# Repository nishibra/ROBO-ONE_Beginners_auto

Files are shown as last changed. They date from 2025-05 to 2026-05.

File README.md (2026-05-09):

# ROBO-ONE Beginners auto

### ROBO-ONE Beginners 競技規則　[競技規則](https://github.com/nishibra/ROBO-ONE_Beginners)
### ROBO-ONE Beginners auto　[機械設計](Mechanical_Design.md)
### ROBO-ONE Beginners auto　[電子回路](Electronic_Circuit.md)

-2025年8月22日 シリアル通信用に分配器を追加しました。
 
### ROBO-ONE Beginners auto　[ソフトウェア](Software.md)

-2026年2月20日　●ToFセンサーで相手を探すサンプル追加　●近藤科学のコントローラーKRS-5FHを使うサンプル追加

-2026年5月9日　●倒立伸子のサンプルプログラムを追加
### ROBO-ONE Beginners movies [動画](https://www.youtube.com/channel/UCuxCMnABbm_D5GusLxcCyIQ)

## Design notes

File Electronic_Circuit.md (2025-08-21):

# ROBO-ONE Beginners 自律型ロボット(RasPi Pico)　Electronic Circuit
## コンセプト
自律型でビジョンを除く必要なセンサーを搭載しました。はんだ付けは極力少なくするようにしました。入出力の拡張も余裕を持たせました。以下は電子回路部分の完成写真です。

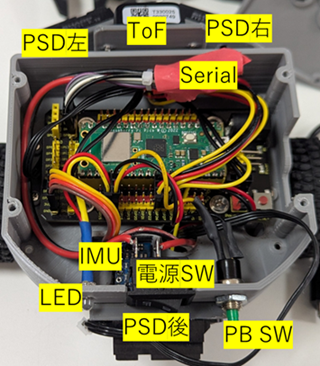
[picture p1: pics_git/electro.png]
  

### Pico拡張ボード
入出力Pinが電源とともに出力されているのでとても便利です。黒:gnd 赤:3.3v 黄:信号

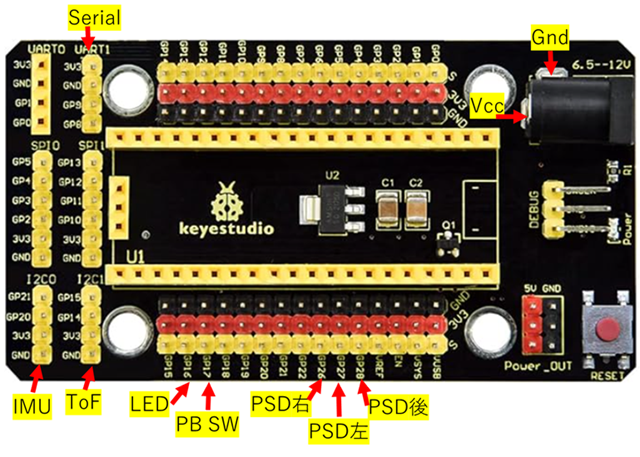
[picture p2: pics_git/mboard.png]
  

[拡張ボードの購入先例](https://www.amazon.co.jp/dp/B0B45YWJH7?ref=ppx_yo2ov_dt_b_fed_asin_title)

### Raspberry Pi Pico
PicoやPico w,pico2,pico2wなどを使用します。PicoW、Pico2Wを使用すれば、Bluetoothによるコントロールプログラムが利用できます。

[Pico-series 仕様](https://www.raspberrypi.com/documentation/microcontrollers/pico-series.html#pico-2-family)

[Picoの購入先例](https://akizukidenshi.com/catalog/g/g117947/)

### Serial変換I/F
サーボモーターを使用するためのシリアル通信を全二重通信から半二重通信に変換するボードです。

[Serial変換I/Fの購入先](https://www.besttechnology.co.jp/modules/onlineshop/index.php?fct=photo&p=299)

#### 配線方法
シリアル変換I/Fの配線状態です。(シリアル変換I/Fボードは仕様変更がありますので配線に当たっては必ずマニアルでご確認ください。)
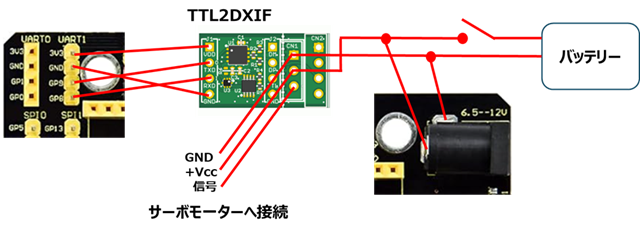
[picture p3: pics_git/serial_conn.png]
serial


(2025年8月22日追加変更)
この配線では回路ではシリアル変換I/Fボードに配線が集中するので分配器を追加しました。シリアル変換I/Fボード側は拡張基板から電源が供給されるので配線はシンプルになります。

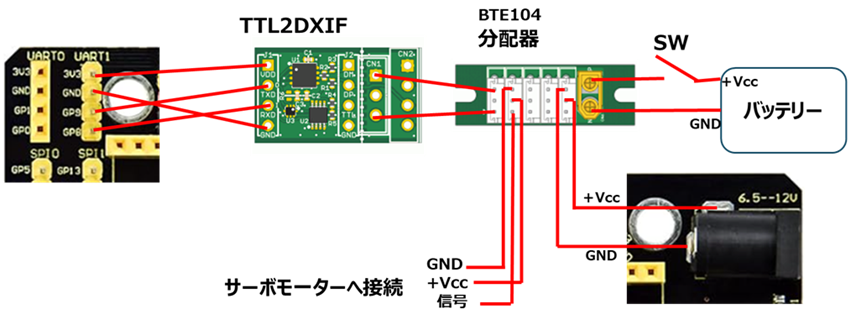
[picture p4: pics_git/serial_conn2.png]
serial


分配器はコネクターをはんだ付けしていないキットを購入すればコネクターの変更によって以下のように近藤科学のサーボや電源コネクターに対応することができます。
  
[分配器の購入先](https://www.besttechnology.co.jp/modules/onlineshop/index.php?fct=photo&p=317)

分配器  

拡張基板に電源供給するためのコネクターをはんだ付けしておきます。コネクターはラジコン用に使われているもので、分配器に接続します。

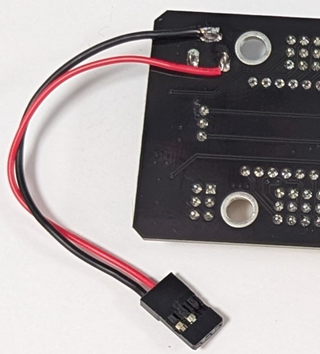
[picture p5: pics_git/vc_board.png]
  

これらを接続すると以下のようになります。

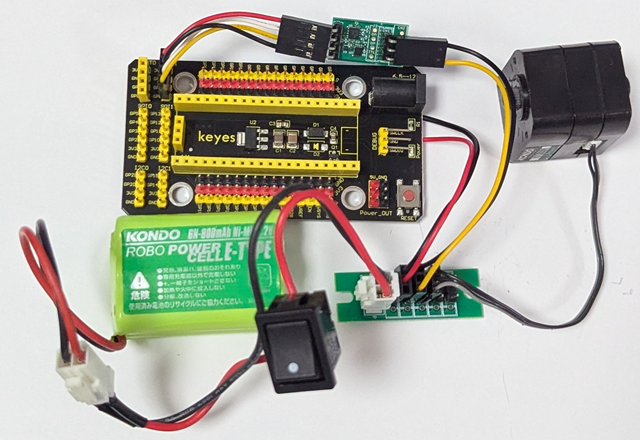
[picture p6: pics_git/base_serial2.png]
serial
  

シリアル変換I/Fボードは拡張基板のシリアルポート1に接続します。
全てのコネクターは方向を間違えないように挿してください。破損の原因となります。

コネクターの作り方については以下のサイトなどをご参照ください。

[コネクターの作り方](https://flyingcattokyo.sakura.ne.jp/MN-016/aa_mn-016.htm)

### PSDセンサー(SHARP製 GP2Y0A21YK0F)
PSD（Position Sensitive Detector）は光が当たった位置に応じて、アナログ信号を出力する受光素子で、距離を計測するセンサーです。出力はアナログ電圧ですのでADC端子に接続します。黒:gnd　赤:3.3v  黄:信号で、ケーブルは黒:gnd　赤:3.3v  白:信号に対応します。このセンサーの推奨電圧は5Vですが3.3Vでも問題なく動作しています。

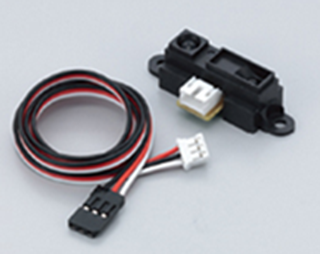
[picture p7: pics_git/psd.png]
psd
  

[購入先](https://kondo-robot.com/product/02002)
```
右　 GP26
左   GP27
後ろ GP28
に接続します。接続方向を間違えないようにしてください。
```
### ToFセンサー(TF-Luna)
光を発射し、それが反射して戻ってくるまでの時間を計測することで、距離を測定するToF(Time of Flight)センサーです。比較的長距離の距離の計測に使用します。このセンサーでは3m程度まで測定できます。

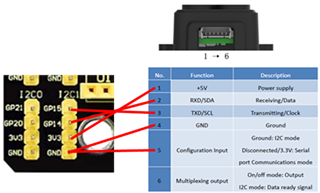
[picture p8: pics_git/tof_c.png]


推奨電圧は5Vですが、3.3Vでも動作を確認しました。

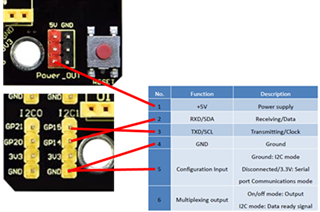
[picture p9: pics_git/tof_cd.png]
  

動作が不安定な場合は拡張ボードから5V電圧が出ていますのでこちらから給電してください。

[購入先](https://www.amazon.co.jp/dp/B087N2JRJ9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)
```
I2C1に接続します。
GP15    scl
GP14    sda
3V3     Vcc
GND     gnd
```

### IMU　9軸センサー(BNO055)
IMU(Inertial Measurement Unit)は、慣性計測装置のことで、3次元の慣性運動（並進運動と回転運動）を検出するために、加速度センサーと角速度（ジャイロ）センサーを組み合わせた装置です。ここではロボットの姿勢(オイラー角)を計測するために使用します。I2C通信で使用します。基板面に垂直方向がヨー軸で基板の長い面に平行な方向がロール軸、短い面に平行な軸がピッチ軸となります。

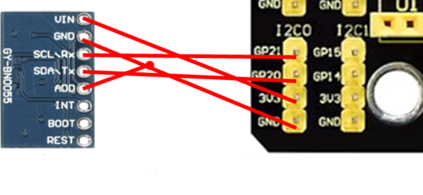
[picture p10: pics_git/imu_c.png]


BNO055ブレークアウトボードにはいろいろあるようなので使用に当たっては注意が必要です。
うまく動作しない場合は以下のサイトをご参照ください。

[モーションセンサBNO055が動かない,I2C接続で認識されないとき](https://trhk.exblog.jp/30642762)

[購入先](https://www.amazon.co.jp/BNO055-%E7%B5%B6%E5%AF%BE%E6%96%B9%E5%90%91%E3%82%BB%E3%83%B3%E3%82%B5%E3%83%BC-%E3%83%9C%E3%83%BC%E3%83%89%E8%A7%92%E5%BA%A6-%E3%82%B8%E3%8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)
```
I2C0に接続します。
GP21    scl
GP20    sda
3V3      Vcc
GND    gnd
```
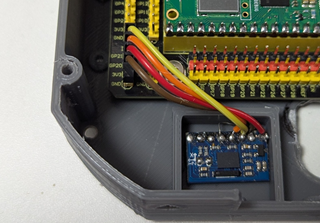
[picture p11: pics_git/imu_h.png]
  

以下のボードも確認しました。同じプログラムで動作します。

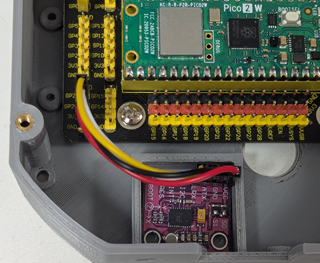
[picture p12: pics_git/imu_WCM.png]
WCMCU055
 

[WCMCU055の購入先](https://www.amazon.co.jp/inscriptions-BNO055-%E3%82%A4%E3%83%B3%E3%83%86%E3%83%AA%E3%82%B8%E3%82%A7%E3%83%B3%E3%83%88-%E5%A7%BF%E5%8B%A2%E3%82%BB%E3%83%B3%E3%82%B5%E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)

使い方は[こちら](https://www.davidpilling.com/wiki/index.php/BNO055)をご参照ください。

秋月電子のBNO055使用9軸センサフュージョンモジュールもテストして見ました。

[秋月電子BNO055の購入先](https://akizukidenshi.com/catalog/g/g116996/)

ボード上でプルアップされていないので、SDA,SCL端子を2kΩ程度の抵抗でプルアップしてください。同じプログラムで動作します。

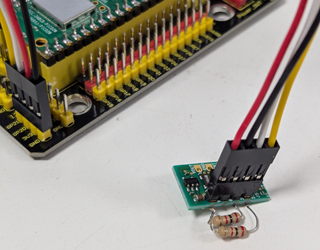
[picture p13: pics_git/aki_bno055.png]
aki_bno055


### Push ボタンSW
押しボタンスイッチです。入力として使います。1KΩ程度の抵抗を追加し、GP17に接続します。

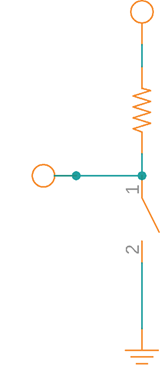
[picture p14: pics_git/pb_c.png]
  
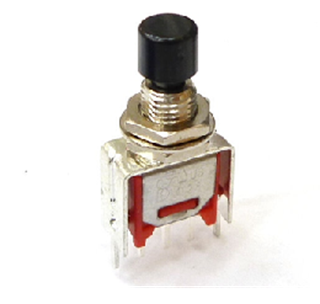
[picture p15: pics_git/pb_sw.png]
  
 
[購入先](https://akizukidenshi.com/catalog/g/g104367/)

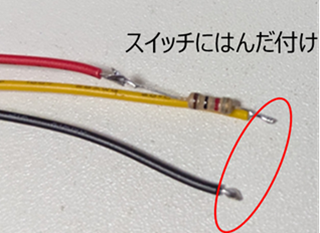
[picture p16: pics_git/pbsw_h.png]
pb2


### LED
発光ダイオードです。1KΩ程度の抵抗を追加して使用します。リードの長い方が一般にアノードです。プラス側に接続します。ここではGP16に接続します。GNDは接続しません。

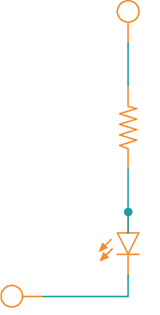
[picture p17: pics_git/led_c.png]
  
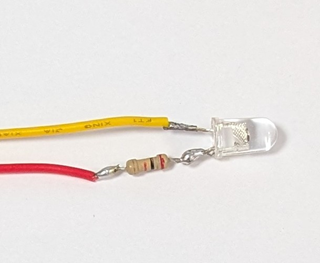
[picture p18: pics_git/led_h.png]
  

[購入先](https://akizukidenshi.com/catalog/g/g104764/)

### 電源SWハーネス
電源用のスイッチです。

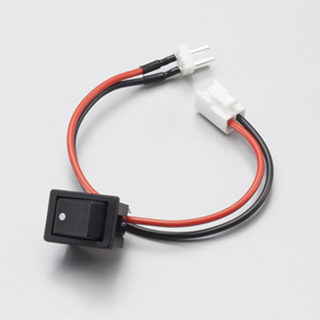
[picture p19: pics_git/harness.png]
harness
  
 
[購入先](https://kondo-robot.com/product/lv_sw_harness)

### ニッケル水素バッテリー
このサイズのニッケル水素バッテリーのみが使用可能です。

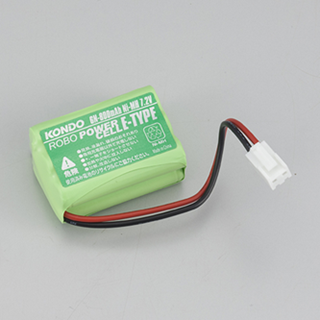
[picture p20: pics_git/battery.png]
bat
  

[購入先](https://kondo-robot.com/product/02335)

### ROBOパワーセル用コネクターセットオス
拡張基板への電源供給用に使用できます。

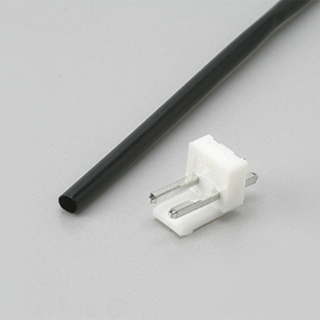
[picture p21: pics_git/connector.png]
con
  
 
[購入先](https://kondo-robot.com/product/01109)

### 電源ケーブルA
拡張基板への電源供給用に使用できます。

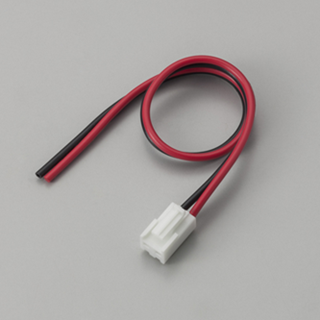
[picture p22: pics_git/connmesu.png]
conm
  

[購入先](https://kondo-robot.com/product/02145)

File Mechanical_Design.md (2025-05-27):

# ROBO-ONE Beginners 自律型ロボット Mechanical Design (機械設計)
## コンセプト
このロボットはRaspberry Pi Picoを使った初心者向けの自律型ロボットです。
__構造は操縦型ロボットと同じプロポーションとし、できるだけ共通化します。__ また発展性を考え、倒立伸子の実験にも対応します。

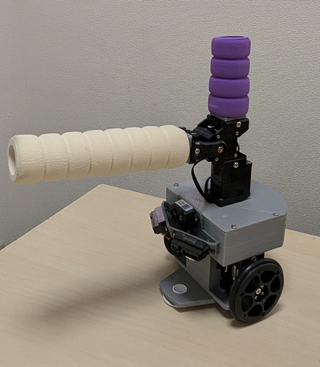
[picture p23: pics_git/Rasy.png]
 

### 全体図
操縦型ロボットとできるだけ部品を共通化、倒立伸子の実験も可能な構造としました。

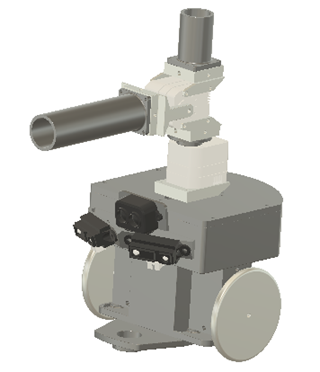
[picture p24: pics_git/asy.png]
 
auto 
auto 

### 足回りパーツ(操縦型と共通)
キャスター部を取り外すと倒立伸子としての使用が可能となります。 __駆動は近藤科学のKRS3301を使用します。バッテリーにはニッケル水素電池のみの使用とします。__
組み立ての相手はKXRパーツのジョイントベースAです。M2-8mmのビスとM2.6-10mmのビスを使用してください。
(詳細の説明の無いビスは近藤科学のものを使用しています。また __PLAに直接ねじを締め付ける場合はタッピングビスを使用します。ただし締め外しの頻度の高い部分はインサートを使用します。__ )

KXRパーツを使ったドライブセットとアームセットを使用します。

[KXRパーツ](https://kondo-robot.com/product-category/parts/kxrparts)

auto 
auto 

[ジョイントベースA](https://kondo-robot.com/product/02300)

[アームサポーター3300A](https://kondo-robot.com/product/02306)

足回りパーツ

auto 
auto 
auto   

### Pico CPU case
センサーを多く付けたためPicoのケースが大きくなりました。
[Pico拡張ボード](pics_git/electro.png)  の締め付けにはM2.6-8mmタッピングビスを使用ます。

auto   
auto   
  
CPUカバーの締め付けを繰り返すとねじが馬鹿になるのでインサートを使用しました。購入の都合でM2.5を使用していますので、M2.5のねじ(近藤科学のM2.6も使用できますが締め付けが少し硬い)を使用するかインサートをM3にしても良いでしょう。ねじ部M3、外径5mmのインサートを使用する場合はボスを大きくしたstlファイル(Cpu_pico_cover_insert_M3-5mm v3.stl,Cpu_pico_case_insert_M3-5mm v4.stl)を準備しましたのでご使用ください。

auto   

[動画](https://www.youtube.com/shorts/zL2C9oKePpQ)

[購入先](https://www.amazon.co.jp/dp/B0DCV9GJND?ref=ppx_yo2ov_dt_b_fed_asin_title)

auto   
auto   

### PSDと ToF　センサーブラケット

PSD 2個とToFセンサーのブラケットです。Cpu-caseにはM2-5mmタッピングビスで締め付けます。センサーはM2-5mm皿タッピングビスで締め付けます。PSD 2個のセンサーは左右へ22°、下へ20°傾いて取り付けられます。ToFセンサーは正面下へ10°傾いて取り付けられます。

auto   

後部センサーブラケットです。Cpu-caseにはM2-5mmタッピングビスで締め付けます。センサーもM2-5mm皿タッピングビスで締め付けます。センサーは下へ20°傾いて取り付けられます。
PSDについてはリングエッジの認識、相手の認識を目的としています。また後ろの相手も認識します。ToFセンサーに関しては少し長い距離を測定します。相手の認識やリングエッジを認識します。IMUと組み合わせることで自己位置の推定も可能となります。

auto  

### Head と Arm(操縦型と共通)
この2点は操縦型と共通です。 組み立ての相手はKXRパーツのジョイントベースAです。M2-8mmのビスを使用して取り付けてください。

auto  
auto  

Head部とArm部には安全や器物保護のためスポンジのドアノブカバーを使用します。
ピンクと紫は半分に切ってHead部に使用します。赤コーナーの場合はピンク、青コーナーは紫です。その他の色はArmに使ってください。Head部は交換しやすくするために締め代を少なくしています。

donb  

[購入先](https://amzn.asia/d/89CXsD9)

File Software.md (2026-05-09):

# ROBO-ONE Beginners 自律型ロボット Software
このロボットはRaspberry Pi Picoを使った初心者向けの自律型ロボットです。MycroPythonを使用してプログラミングします。

## 開発環境
- PCのOS
  Windows
- 統合開発環境
  Thonny
- 開発言語
  Micro Python

### Thonnyのインストール

[Thonnyのインストール【Windows編】](https://sanuki-tech.net/and-more/2022/install-thonny-python-ide/)

### Raspberry Pi Pico

[Pico-series Microcontrollers](https://www.raspberrypi.com/documentation/microcontrollers/pico-series.html#pico-2-family)

### picoの開発の流れ

- リセントボタンを押しながら電源をいれる。
- PCにPICOのフォルダーを認識
- UF2フィルをダウンロードし書き込み
- Thonnyを起動
- ツールオプションの設定
- サンプルプログラムをロード/実行
- main.pyとしてpicoに保存(自動起動)

### UF2ファイル
UF2は-USB Flashing Format(UF2)-Microsoftが開発したマイコン書き込み用のファイルフォーマットです。以下のサイトより適切なuf2ファイルをダウン―ドしてください。

[Download the correct MicroPython UF2 file for your board](https://www.raspberrypi.com/documentation/microcontrollers/micropython.html)

### Picoの起動

UF2ファイルをダウンロードし、picoのフォルダーにコピペしてください。電源を入れるとPicoが起動します。
Thonnyにて以下を設定します。

- ConfigでインタープリターをMicroPython(Raspberry Pi Pico)に設定します。ポートが表示されていることを確認します。
- MicroPython(Raspberry Pi Pico)のポートに接続します。
- Shell画面が以下の要になれば設定完了です。
- すでにプログラムが書き込まれているときはThonnyのストップボタンをおすか、Pico拡張ボード上のリセットボタンを押した後、ポートに再接続します。
```
MicroPython v1.25.0 on 2025-04-15; Raspberry Pi Pico W with RP2040
Type "help()" for more information.
>>> 
```
## サンプルプログラム
### 押しボタンSW入力とLed点滅
example/io/switch_led_test.pyはスイッチ入力によりLEDを点灯するプログラムです。

### ADCとPSD入力
example/psd/psd_test.pyはPSDセンサーの出力電圧をADコンバーターにより取り込みその電圧を距離に変換するプログラムです。

### Serial Servoのコントロール
example/krs/krs_driver.pyは近藤科学のKRSサーボモーターをコントロールするためのプログラムです。

[KRS-3301 ICS](https://kondo-robot.com/product/krs-3301-ics)

[ICS3.5/3.6 ソフトウェアマニュアルコマンドリファレンス](chrome-extension://efaidnbmnnnibpcajpcglclefindmkaj/https://kondo-robot.com/w/wp-content/uploads/ICS3.5_3.6_SoftwareManual_2_9.pdf)

ソフトウェアマニュアルコマンドリファレンスを参考に必要な機能のみプログラムしました。
サーボのボーレイトはは1250000bpsに設定されているものとして以下のように初期化しています。
```python
class KRSdriver():
  def __init__(self):
   #set serial
    self.con = UART(1, baudrate=1250000, tx=Pin(8), rx=Pin(9))
    self.con.init(bits=8, parity=0, stop=1,timeout=50)
```
mainプログラムで各軸のポジションの取得やモーターの回転方向などのテストができます。
```python
if __name__ == '__main__':
  print('Start KRS Test')
  krs=KRSdriver()
#
  get_position_all()　# すべての軸のポジションを取得
  arm_set() # アームのセットポジションへ移動
  drive_set() # モーターを直進後転回
```
またサーボモーターの設定は以下のようにしています。

SERVO_SET

### I2cスキャナー
example/i2c/i2c_2ch_scaner.pyはI2Cに接続されているデバイスのアドレスを以下のように表示します。
```
>>> %Run -c $EDITOR_CONTENT
MPY: soft reboot
I2C0-I2C1 SCANNER
i2c0 devices found: 1
I2C0  address:  0x28
i2c1 devices found: 1
I2C1  address:  0x10
>>> 
```

[参考 Raspberry Pi Pico: I2C Scanner (MicroPython) – Finding the Address of I2C Devices](https://randomnerdtutorials.com/raspberry-pi-pico-i2c-scanner-micropython/)

### IMU BNO055-driver
以下はbno055のmicropython driverです。
```
example/imu/bno055_test.py
example/imu/bno055_base.py
example/imu/bno055.py
```
このプログラムは以下のサイトのものを使わせて頂きました。[Adafruit 9-DOF Absolute Orientation IMU Fusion Breakout - BNO055](https://www.adafruit.com/product/2472)がベースとなっているとのことでこちらのボードを使うとより良いでしょう。

[参照 micropython-bno055](https://github.com/micropython-IMU/micropython-bno055)

BNO055のaddressは28または29となります。このプログラムでは下記の二か所のアドレスを変更する必要があります。
```
bno055_base.py の81行目
  def __init__(self, i2c, address=0x28, 
```
および
```
bno055.pyの118行目
　def __init__(self, i2c, address=0x28, crystal=True, 
```
の二か所です。i2c_scanner.pyでご確認の上変更してください。

#### cariblationの方法
キャリブレーションの方法は[BNO055メモ](https://qiita.com/yomori/items/95101a8792287263792b)によると
```
- 加速度計のキャリブレーション
デバイスを数秒間、6つの異なる安定した位置に置く。位置の変更はゆっくりと動かすようにする。6つの安定した位置は任意の方向でよいが、装置が少なくとも1回はX,Y,Z軸に垂直になるようにする。
- ジャイロスコープのキャリブレーション
デバイスを数秒間、単一の安定した位置に置く。
- 磁力計のキャリブレーション
磁力計はHard-iron歪みとSoft-iron歪みの両方の影響を受けるが、多くの場合、Hard-ironの影響が原因。
装置全体をランダムな動き（たとえば、空中に数字の「8」を書くなど）をいくつか行うことでHard-ironに対するキャリブレーションを行う。
- CALIB_STATレジスタで、加速度計のキャリブレーション状態を確認できる。すべてが3になると終了する。
```
だそうです。  試合中にはキャリブレーションはできないので、事前にやっておく必要があります。またはキャリブレーションを行わずにセット位置を基準に動作させるのが良いでしょう。

example/imu/bno055_test.pyを実行することでキャリブレーションの有無を確認できます。calibrated = Falseで実行するとキャリブレーションを開始します。出力は絶対位置となります。
calibrated = Trueではキャリブレーションはせずに出力は相対位置となります。起動時の姿勢をヨー角0°とします。

### ToF センサー TF-Lunaライブラリー
以下は[TF-Luna LiDAR Range Sensor](https://www.waveshare.com/wiki/TF-Luna_LiDAR_Range_Sensor)を使用するためのライブラリーです。
```
example/tof/tof_test.py
example/tof/tof_max_mini.py
example/tof/lider.py
```
以下のサイトのライブラリーを使わせて頂きました。
[参照 tf-luna-micropython](https://github.com/davmoz/tf-luna-micropython)

[参考サイト class I2C – a two-wire serial protocol](https://docs.micropython.org/en/latest/library/machine.I2C.html)

### BLE 通信ライブラリー
以下はBLEの通信ライブラリーです。
```
example/ble/ble_test.py
example/ble/ble_simple_peripheral.py
example/ble/ble_advertising.py
```
以下のサイトから通信ライブラリーを使わせて頂きました。
[参照 Pi Pico W でBluetooth Low Energy（BLE）を試してみる](https://wisteriahill.sakura.ne.jp/CMS/WordPress/2023/10/09/pi-pico-bluetooth-low-energy-ble/)

example/ble/ble_test.pyを実行して、接続確認をしましょう。
example/ble/ble_simple_peripheral.pyの36行目のnameを変更しておくとbluetoothをscanしたときにこの名前が現れます。
スマホのアプリからSerial Bluetooth Terminal(以下のアイコン)をダウンロードしてこれに接続します。このterminalから入力したテキストがシェルに表示されれば接続テスト完了です。

SERVO_SET

### BLEを使ったスマホによるロボットコントロール
- [スマホによる操縦プログラム](https://www.youtube.com/shorts/bfC331REHko)
- [PSDによるリングエッジの認識と回避](https://www.youtube.com/shorts/sOUL5hm2Ak4)
- [PSDによる相手の認識と攻撃](https://www.youtube.com/shorts/i9BcCGD1VBw)

example/beginners/robo_beginners.pyはスマホによるロボットコントロールプログラムです。
スマホのアプリBaconを使用します。アプリからダウンロードしてください。以下のアイコンです。

SERVO_SET

コントロール画面は以下のように押したときにコマンドを発行し、離した時に発行されるコマンドを設定します。
動画の様な画面を自由に作ってください。

SERVO_SET

### PSDとToFセンサーを使用したサンプルプログラム
ToFセンサーを追加し相手を探す簡単なサンプルプログラムを追加しました。
```
example/beginners/robo_beginners_tof.py
```
Tofセンサーは1m程度先を見るように設定しリング外のものに反応しないように、また外乱光の影響を受け難いようにします。
相手がいるときはまっすぐ進みます。近づけば、PSDセンサーが反応し相手を打突します。相手がいない時はくねくねとターンを繰り返しながら相手を探します。

- [ToFセンサーで相手を探す動画](https://youtu.be/fS7ZChnerrg)

Baconは写真のように上段をアームに、下段を足回りにそれぞれ矢印の方向に動作するように設定しました。またAボタンでauto、Bボタンで操縦型などと自由に設定してください。

Bacon_SET

### 近藤科学のコントローラーKRS-5FHを使う。

1). 接続と基本設定

KRS-5FH（送信機・受信機セット）を使用するには、まず物理的な接続と設定が必要です。

KRS-5FH

接続方法: 受信機をサーボモータと同じように**デイジーチェーン（数珠つなぎ）**で接続します。

通信設定:
- ID: 31（固定）
- ボーレート: 接続しているサーボモータの設定に合わせてください。

2). ドライバーの更新内容（krs_driver_v2_0.py）
```
example/krs/krs_driver_v2_0.py
```
新しいドライバーでは、以下の2つの機能が追加されています。

- KRS-5FHのデータ取得: 送信機からのボタン入力を読み取ります。
- 不揮発性メモリへのアクセス: サーボ（KRS）の内部パラメータを直接書き換えられるようになりました。

3). KRS-5FHからデータを取得する方法

ドライバー内の get_5fh() ルーチンを呼び出すと、ボタンの押下状態が 16bit（2バイト） のデータとして返ってきます。
- 仕組み: 各ボタンが16bitの各ビットに対応しており、ボタンを押すとそのビットが 1（ON）になります。
- サンプルコード:以下のコードを走らせ、送信機のボタンを押すと、対応する数値がコンソールに表示されます。

Python
```python
from krs_driver_v2_0 import *
import time
# ドライバーの初期化
krs = KRSdriver()
while True:
    # 送信機のボタンデータを取得（2バイト分）
    a, b = krs.get_5fh()
    print(f"Byte A: {a}, Byte B: {b}")
    # 0.002秒待機
    time.sleep(0.002)
```
4). 活用のアドバイス
取得した数値（a, b）をプログラム内で比較・判定することで、特定のボタンが押された時に「前へ移動する」「面を打つ」といったアクションを割り当て、ロボットを自由自在に操縦できるようになります。

### IMUの活用事例
#### Pich軸制御　(倒立伸子)
[Pich動画](https://www.youtube.com/shorts/UjHwfoPYoFk)

[Pitch2動画](https://www.youtube.com/shorts/Del15TIizIo)

サンプルプログラムは以下に置きました。

/example/balance/self_balanced

#### Roll軸制御
[Roll動画](https://www.youtube.com/shorts/StgpTMR23V4)

#### Yaw軸制御
[Yaw](https://www.youtube.com/shorts/aTl3Kq1fJ40)

#### PIDの最適化
[強化学習動画](https://www.youtube.com/watch?v=8uTVi8vXCB4)

サンプルプログラムは以下に置きました。

/example/balance/rein_bestPID.py

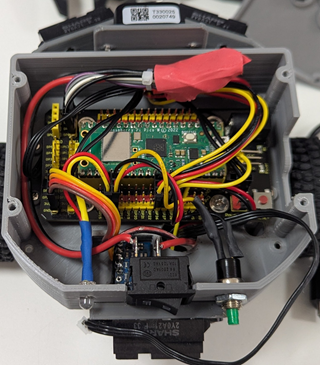
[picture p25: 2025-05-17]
pics_git/ele_all.png

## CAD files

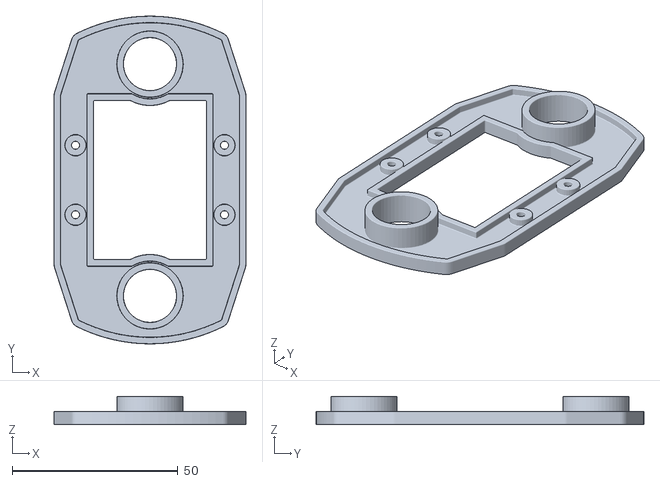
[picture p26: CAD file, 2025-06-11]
stl/Chassis_B_70 v2.stl
58.0 x 99.0 x 8.50

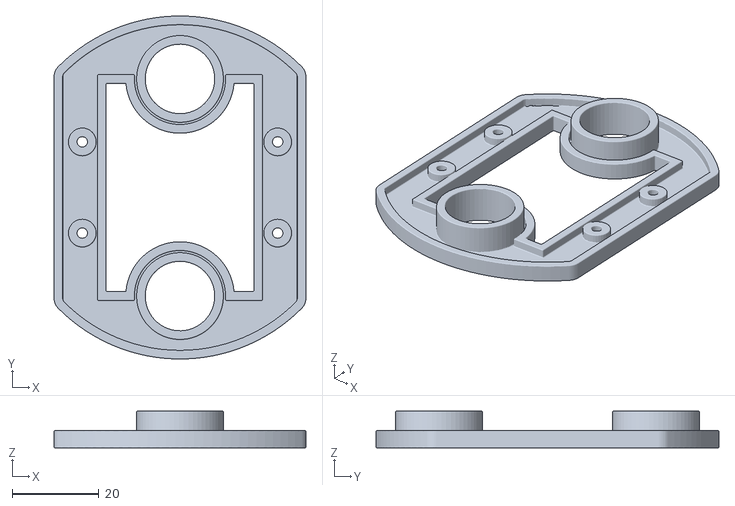
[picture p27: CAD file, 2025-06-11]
stl/Chassis_B_50 v2.stl
58.0 x 79.0 x 8.50

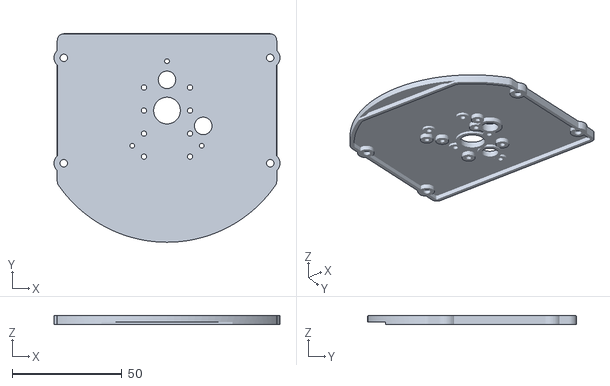
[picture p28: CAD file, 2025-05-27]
stl/Cpu_pico_cover_insert_M3-5mm v3.stl
103.0 x 95.0 x 4.00

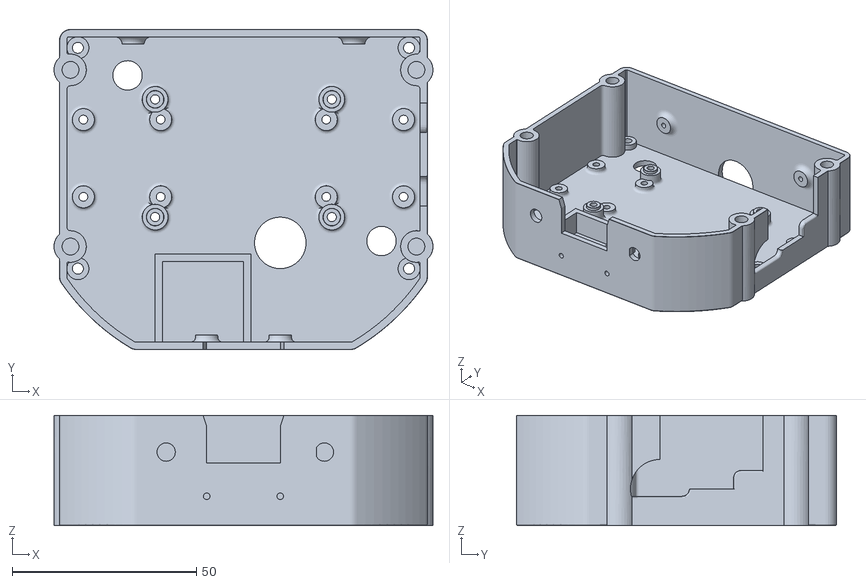
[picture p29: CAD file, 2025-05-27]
stl/Cpu_pico_case_insert_M3-5mm v4.stl
103.0 x 87.0 x 30.0

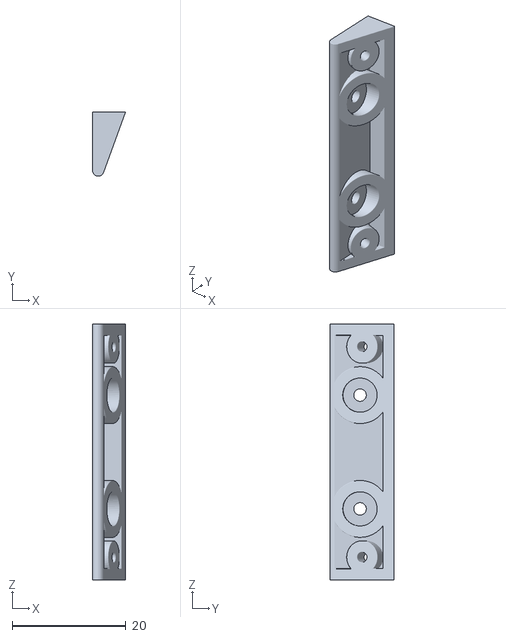
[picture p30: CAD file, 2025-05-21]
stl/Psd1_bkt v6.stl
5.78 x 11.3 x 45.0

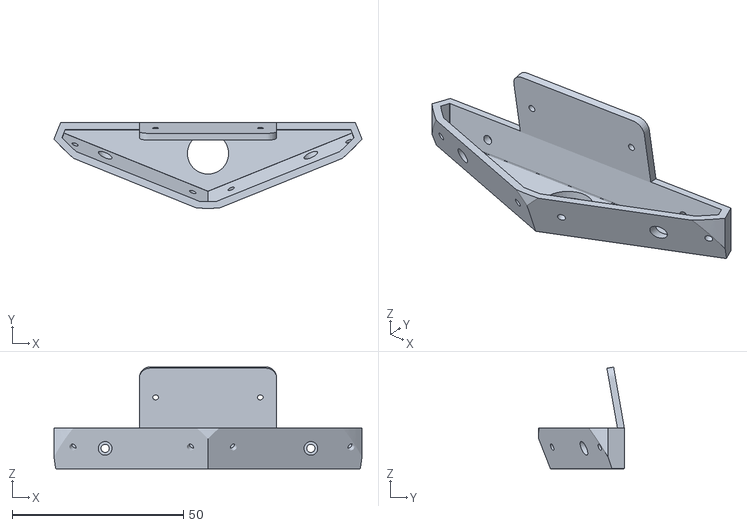
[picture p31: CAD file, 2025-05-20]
stl/Psd2_Tof_bkt v11.stl
89.9 x 25.0 x 29.7

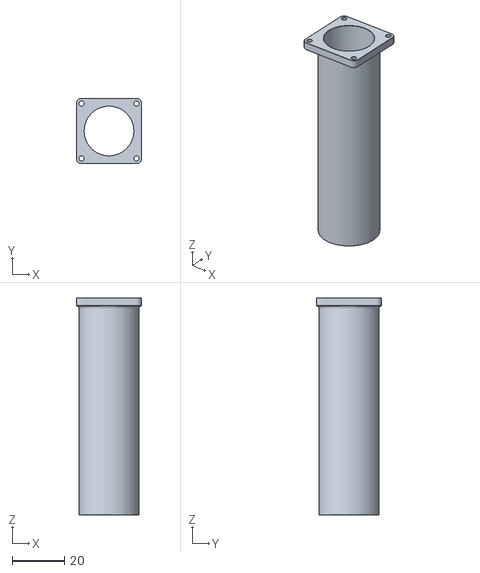
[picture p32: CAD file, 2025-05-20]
stl/Arm v1.stl
25.0 x 25.0 x 83.0

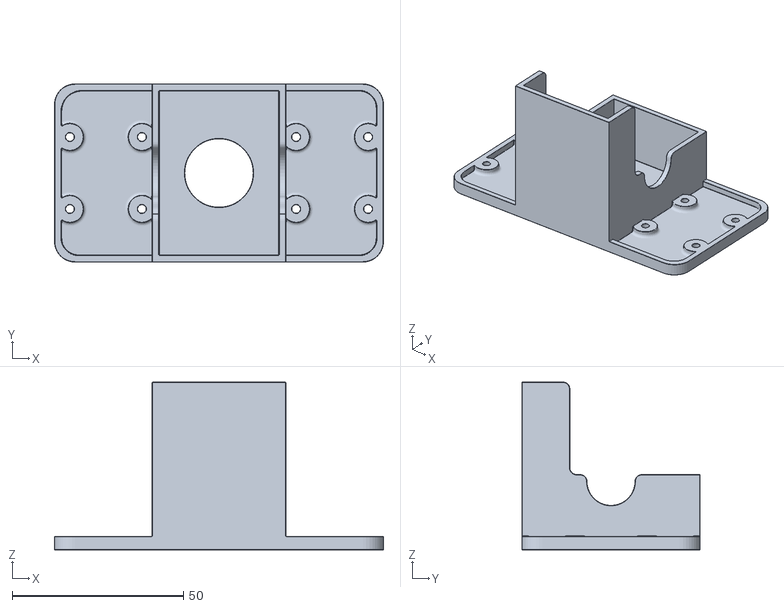
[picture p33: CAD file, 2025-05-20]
stl/Chassis_A.stl
96.0 x 52.0 x 49.0

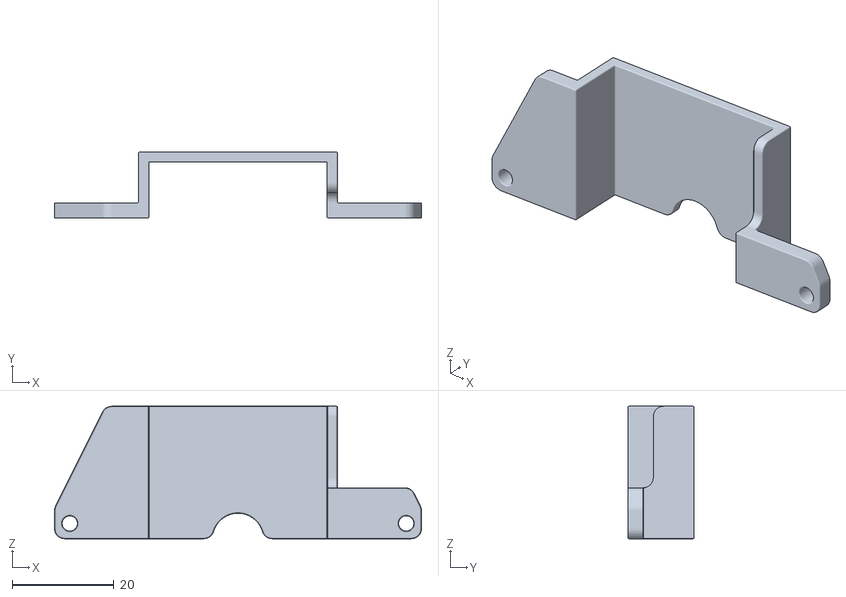
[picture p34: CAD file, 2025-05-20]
stl/Battery_cover.stl
72.0 x 13.0 x 26.0

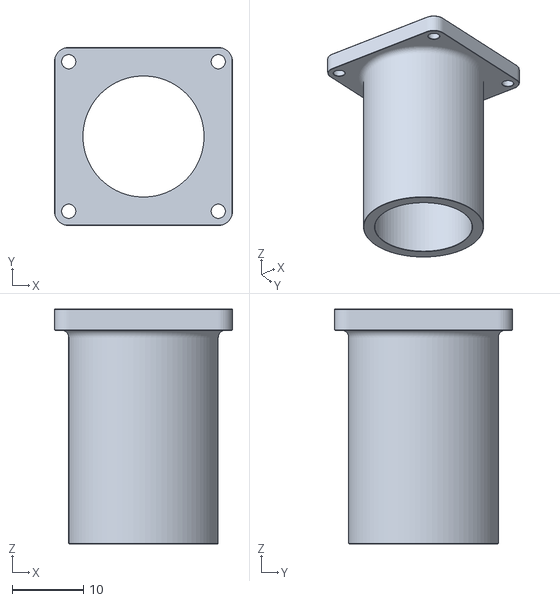
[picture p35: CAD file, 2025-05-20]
stl/Head v1.stl
25.0 x 25.0 x 33.0

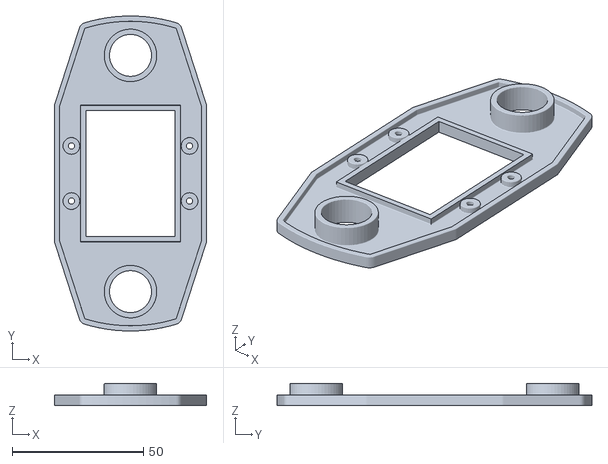
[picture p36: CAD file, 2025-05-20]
stl/Chassis_B.stl
58.0 x 120.0 x 8.50

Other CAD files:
stl/Cpu_pico_case v49.stl
stl/Cpu_pico_cover v29.stl
fd3/Psd1_bkt.f3d
fd3/Psd2_Tof_bkt.f3d

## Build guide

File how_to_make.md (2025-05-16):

# ROBO-ONE Beginners 自律型ロボット(RasPi Pico)

20250506 ARRC_西村

このロボットはRaspberry Pi Picoを使った初心者向けの自律型ロボットです。操縦型ロボットとできるだけ共通化するとともに、倒立伸子の実験も可能とした構造とします。

## <メカ>
### 全体図
操縦型ロボットとできるだけ共通化、倒立伸子の実験も可能な構造としました。

auto 
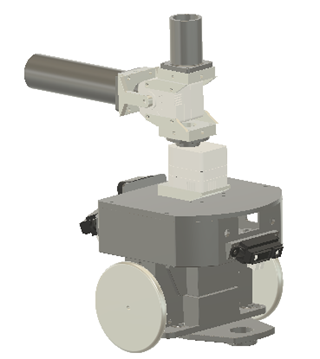
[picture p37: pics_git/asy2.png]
 
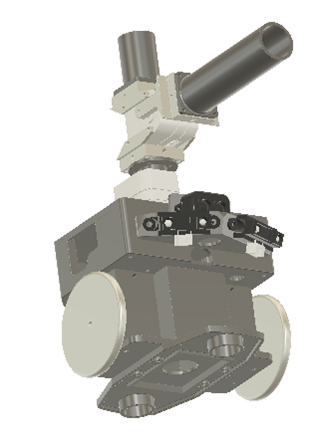
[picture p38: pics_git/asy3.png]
 

### 足回りパーツ
キャスター部を取り外すと倒立伸子としての使用が可能となります。駆動は近藤科学のKRS3301を使用します。バッテリーにはニッケル水素電池のみの使用とします。

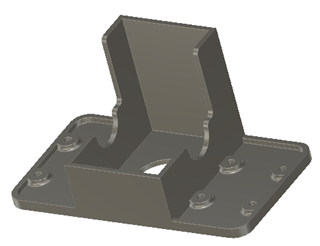
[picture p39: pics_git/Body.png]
 
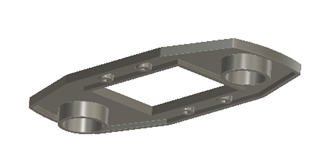
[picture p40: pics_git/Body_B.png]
 
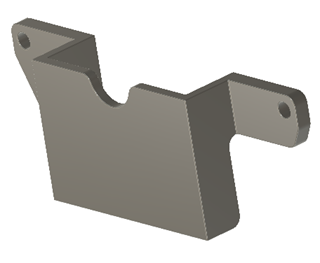
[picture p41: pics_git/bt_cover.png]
   

### Pico CPU case
センサーを多く付けたためPicoのケースが大きくなりました。

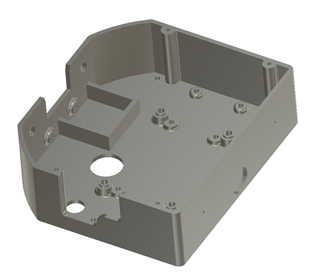
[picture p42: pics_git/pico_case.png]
   
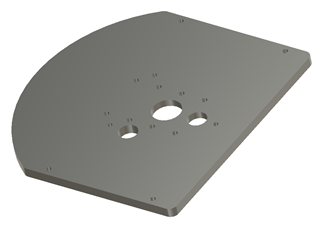
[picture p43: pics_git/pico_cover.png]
   
  
CPUカバーの締め付けを繰り返すとねじが馬鹿になるのでインサートを使用しました。

### PSDdと ToF　センサーブラケット

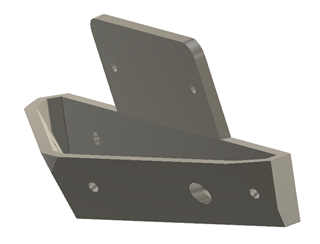
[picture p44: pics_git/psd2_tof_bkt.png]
   　　 
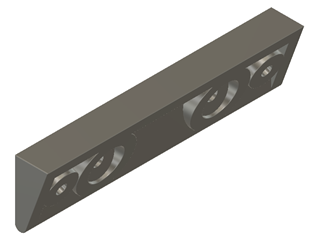
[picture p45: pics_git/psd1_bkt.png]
  

### Head と Arm
この2点は操縦型と共通です。

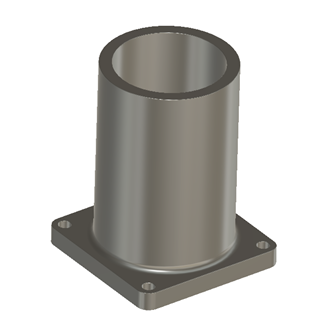
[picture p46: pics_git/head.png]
  
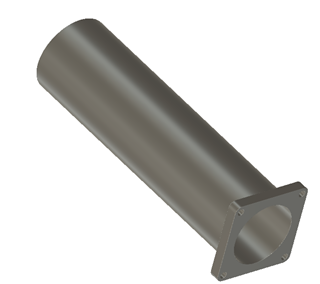
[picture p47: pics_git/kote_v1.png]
  

## <ハード>

### Pico拡張ボード
入出力Pinが電源とともに出力されているのでとても便利です。

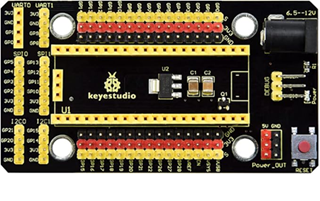
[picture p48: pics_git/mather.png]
mather
  

[購入先](https://www.amazon.co.jp/dp/B0B45YWJH7?ref=ppx_yo2ov_dt_b_fed_asin_title)

### Raspberry Pi Pico
PicoやPico w,pico2,pico2wなどを使用します。Pico2W、Pico2Wを使用すれば、Bluetoothによるコントロールプログラムが使用できます。
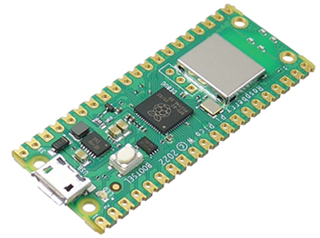
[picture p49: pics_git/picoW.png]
pico
  

[購入先](https://akizukidenshi.com/catalog/g/g117947/)

### Serial変換I/F
サーボモーターを使用するためのシリアル通信の半二重通信から全二重通信に変換するボードです。

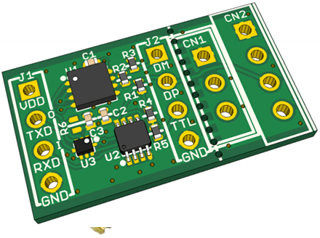
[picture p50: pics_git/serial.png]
serial
  

[購入先](https://www.besttechnology.co.jp/modules/onlineshop/index.php?fct=photo&p=299)

#### 配線方法
シリアル変換基板の配線状態です。

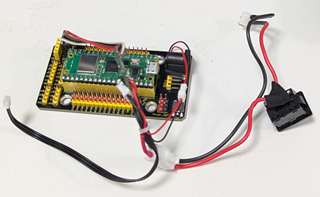
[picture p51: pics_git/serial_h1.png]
serial
  

拡張基板に電源供給するためのコネクターをはんだ付けします。

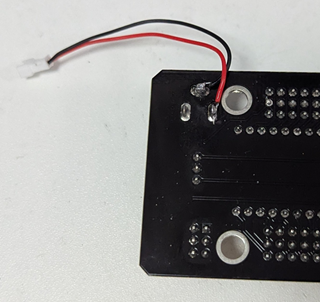
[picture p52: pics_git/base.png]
  

シリアル変換基板のはんだ付けした状態です。

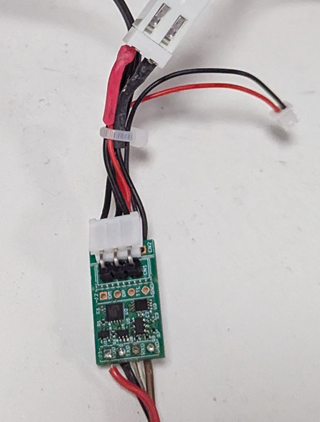
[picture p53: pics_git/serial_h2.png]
serial
  
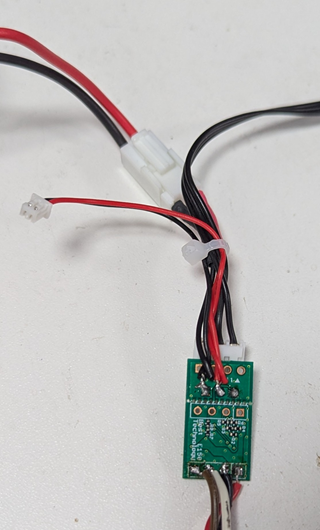
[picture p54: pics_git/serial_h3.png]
serial
  
 
シリアルポート1に接続します。

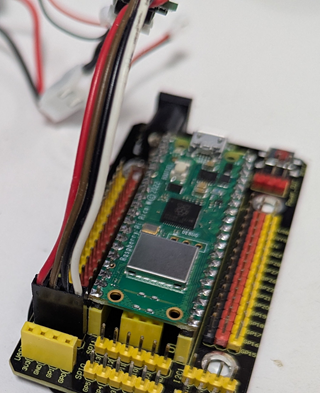
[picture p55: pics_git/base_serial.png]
serial
  

### PSDセンサー
距離を計測するPSDセンサーです。出力はアナログ電圧ですのでADC端子に接続します。

psd  

[購入先](https://kondo-robot.com/product/02002)
```
右　 GP26
左   GP27
後ろ GP28
に接続します。
```
### TOFセンサー
距離を測定するTOFセンサーです。比較的長距離の距離の計測に使用します。

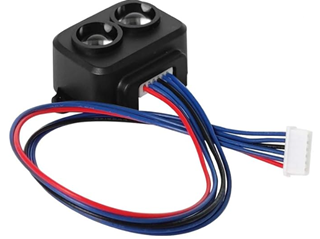
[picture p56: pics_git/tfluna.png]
tof
  

[購入先](https://www.amazon.co.jp/dp/B087N2JRJ9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)
```
I2C1に接続します。
GP15    scl
GP14    sda
3V3     Vcc
GND     gnd
```

### IMU　9軸センサー
オイラー角の計測するためのセンサーです。I2C通信で使用します。

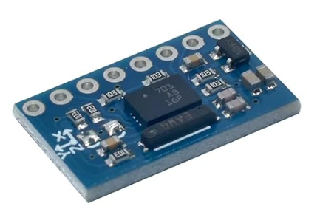
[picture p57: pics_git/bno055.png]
  

[購入先](https://www.amazon.co.jp/BNO055-%E7%B5%B6%E5%AF%BE%E6%96%B9%E5%90%91%E3%82%BB%E3%83%B3%E3%82%B5%E3%83%BC-%E3%83%9C%E3%83%BC%E3%83%89%E8%A7%92%E5%BA%A6-%E3%82%B8%E3%8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)
```
I2C0に接続します。
GP21    scl
GP20    sda
3V3      Vcc
GND    gnd
```
imu  

### Push ボタンSW
押しボタンスイッチです。入力として使います。

pb  
 
[購入先](https://akizukidenshi.com/catalog/g/g104367/)

pb2

1KΩ程度の抵抗を追加し、GP16に接続します。外側から締め付けるタイプを使用すると組み立てる前にはんだをしておくことが出来ます。

### LED
発光ダイオードです。1KΩ程度の抵抗を追加して使用します。リードの長い方が一般にアノードです。プラス側に接続します。

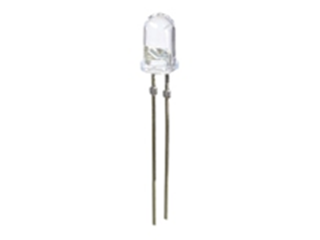
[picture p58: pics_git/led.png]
  

[購入先](https://akizukidenshi.com/catalog/g/g103261/)

led  

GP17に接続する。GNDは接続しません。

### 電源SWハーネス
電源用のスイッチです。

harness  
 
[購入先](https://kondo-robot.com/product/lv_sw_harness)

### ニッケル水素バッテリー
このサイズのニッケル水素バッテリーのみが使用可能です。

bat  

[購入先](https://kondo-robot.com/product/02335)

### ROBOパワーセル用コネクターセットオス
拡張基板への電源供給用に使用します。

con  
 
[購入先](https://kondo-robot.com/product/01109)

### 電源ケーブルA
拡張基板への電源供給用に使用します。

conm  

[購入先](https://kondo-robot.com/product/02145)

## <ソフト>
プログラムに関しては下記概ね確認済みです。少しずつ公開していきます。

### 開発環境
OS
Windows PC
開発
Thonny
開発言語
Micro Python

Thonnyのインストール
　Config等
Picoの設定
Micro Pythonの初期設定

サンプルプログラム
-押しボタン入力とLed点滅

-ADCとPSD入力

-Serial Servoのコントロール

-PSDによるリングエッジの認識と回避

-PSDによる相手の認識と攻撃

-IMUライブラリー

-ToFライブラリー

-ToFとIMUによる相手認識

-倒立伸子の制御

-BLE 通信ライブラリー

-BLEを使ったスマホによるロボットコントロール

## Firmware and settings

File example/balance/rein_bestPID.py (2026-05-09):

#
from machine import Pin, I2C, PWM
import time
import random
from krs_driver_v2_0 import *
import json
#from oled64_class import *
#oled=OLEDdriver()
#oled.logo()

# BNO055のI2Cアドレス
from bno055 import *
i2c = machine.I2C(0, sda=machine.Pin(20), scl=machine.Pin(21)) 
imu = BNO055(i2c)
time.sleep(0.02)
calibrated =True# False #      
while calibrated == False:     
    calibrated = imu.calibrated()
    print('Calibration required: sys {} gyro {} accel {} mag {}'.format(*imu.cal_status()))
    time.sleep(0.02)
#------------------------------
# サーボモーターの設定
#servo id
id_r=1
id_l=2
id_pan=3
id_tilt=4
#
ctr=7500#3500--11500
ctl=7500#3500--11500
ct_pan=6200
ct_tilt=8000
#
krs=KRSdriver()
#
def free():
    krs.read_position_set_free(id_r)
    krs.read_position_set_free(id_l)
    krs.read_position_set_free(id_pan)
    krs.read_position_set_free(id_tilt)
#
def drive(r_sp,l_sp):
    if r_sp>4000:
        r_sp=4000
    elif r_sp<-4000:
        r_sp=-4000
    if l_sp>4000:
        l_sp=4000
    elif l_sp<-4000:
        l_sp=-4000                    
    krs.set_position_ret(id_r,ctr-r_sp)
    krs.set_position_ret(id_l,ctl+l_sp)
#
def arm(pan,tilt):
    krs.set_position_ret(id_pan,ct_pan+pan)
    krs.set_position_ret(id_tilt,ct_tilt+tilt)
#
# PID制御クラス (ゲインは外部から設定できるように変更)
class PIDController:
    def __init__(self, kp, ki, kd, setpoint=-8.0):
        self.kp = kp
        self.ki = ki
        self.kd = kd
        self.setpoint = setpoint
        self.previous_error = 0
        self.integral = 0
#
    def update(self, current_value, dt):
        error = self.setpoint - current_value
        self.integral += error * dt
        derivative = (error - self.previous_error) / dt
        output = self.kp * error + self.ki * self.integral + self.kd * derivative
        self.previous_error = error
        return output
#
    def reset(self):
        self.integral = 0
        self.previous_error = 0
#
# PIDゲインの候補 (非常に少ない数で試す)
KP_CANDIDATES = [1,2]
KI_CANDIDATES = [5,10,15]
KD_CANDIDATES = [0.3,0.5]
ALL_ACTIONS = [(kp, ki, kd) for kp in KP_CANDIDATES for ki in KI_CANDIDATES for kd in KD_CANDIDATES]
NUM_ACTIONS = len(ALL_ACTIONS)

# 状態の離散化 (非常に粗い)
def discretize_state(pitch, angular_velocity):
    if pitch < -10:
        pitch_state = 0
    elif pitch < -2:
        pitch_state = 1
    elif pitch < 2:
        pitch_state = 2
    elif pitch < 10:
        pitch_state = 3
    else:
        pitch_state = 4
#
    if angular_velocity < -5:
        vel_state = 0
    elif angular_velocity < 5:
        vel_state = 1
    else:
        vel_state = 2
#
    return (pitch_state, vel_state)
#
# Qテーブルの初期化 (状態数 x 行動数)
NUM_PITCH_STATES = 5
NUM_VEL_STATES = 3
Q_TABLE = [[0.0 for _ in range(NUM_ACTIONS)] for _ in range(NUM_PITCH_STATES * NUM_VEL_STATES)]
#
def get_q_value(state, action_index):
    state_index = state[0] * NUM_VEL_STATES + state[1]
    return Q_TABLE[state_index][action_index]
#
def set_q_value(state, action_index, value):
    state_index = state[0] * NUM_VEL_STATES + state[1]
    Q_TABLE[state_index][action_index] = value
#
# ε-greedy法による行動選択
EPSILON = 0.1
def select_action(state):
    if random.random() < EPSILON:
        return random.randint(0, NUM_ACTIONS - 1)
    else:
        state_index = state[0] * NUM_VEL_STATES + state[1]
        max_q = -float('inf')
        best_action_index = 0
        for i in range(NUM_ACTIONS):
            if Q_TABLE[state_index][i] > max_q:
                max_q = Q_TABLE[state_index][i]
                best_action_index = i
        return best_action_index
#
# 報酬関数の設計 (非常に単純な例)
def get_reward(pitch):
    if abs(pitch) < 5:
        return 1.0
    elif abs(pitch) < 15:
        return 0.1
    else:    
        return -1.0
#
# 学習率と割引率
ALPHA = 0.1 #学習率
GAMMA = 0.9 #割引率
kp_best=1
ki_best=10
kd_best=0.1
rw_best=-100
#
if __name__ == "__main__":
    free()
    if calibrated == True:
        pid_controller = PIDController(0, 0, 0) # 初期ゲインは0
        last_time = time.ticks_ms()
        reward=0
        #
        try:
            for episode in range(20): # 学習エピソード数
                #print(f"Episode: {episode}")
                pid_controller.reset()
                total_reward = 0
                free()
                time.sleep(1) # 初期静止時間
#
                for step in range(200): # 1エピソードのステップ数
                    current_time = time.ticks_ms()
                    dt = (current_time - last_time) / 1000.0
                    last_time = current_time
                    eu=imu.euler()
                    pitch = eu[1]

                    angular_velocity = 0 # 角速度の取得はBNO055のデータから別途取得する必要があります

                    if pitch is not None:
                        current_state = discretize_state(pitch, angular_velocity)
                        action_index = select_action(current_state)
                        kp, ki, kd = ALL_ACTIONS[action_index]
                        pid_controller.kp = kp
                        pid_controller.ki = ki
                        pid_controller.kd = kd

                        control_output = pid_controller.update(pitch, dt)
                        #print(dt,pitch)
                        factor = 20
                        left_speed =int(control_output * factor)
                        right_speed =int(control_output * factor)
                        drive(right_speed,left_speed)
                        
                        reward = get_reward(pitch)
                        total_reward += reward
                        eu=imu.euler()
                        next_pitch = eu[1]
        
                        next_angular_velocity = 0#gy[0] # 角速度の取得

                        if next_pitch is not None:
                            next_state = discretize_state(next_pitch, next_angular_velocity)
                            best_next_q = -float('inf')
                            for i in range(NUM_ACTIONS):
                                q_value = get_q_value(next_state, i)
                                if q_value > best_next_q:
                                    best_next_q = q_value

                            old_q = get_q_value(current_state, action_index)
                            new_q = old_q + ALPHA * (reward + GAMMA * best_next_q - old_q)
                            set_q_value(current_state, action_index, new_q)

                        #time.sleep_ms(5)

                        if abs(pitch) > 20: # 倒れたと判定
                            break
                if rw_best<total_reward:
                    rw_best=total_reward
                    kp_best=kp
                    ki_best=ki
                    kd_best=kd
                print(f"Ep:{episode} tr:{total_reward} kp:{kp} ki:{ki} kd:{kd}")
                EPSILON = max(0.01, EPSILON * 0.99) # εを徐々に減らす
                free()

        
            # 学習済みQテーブルをJSON形式で保存
            with open("q_table.json2", "w") as f:
                json.dump(Q_TABLE, f)
            print("Qテーブルの学習完了とJSON保存")

            pid_controller.kp = kp_best
            pid_controller.ki = ki_best
            pid_controller.kd = kd_best
            pitch=0
            print(kp_best,ki_best,kd_best)
            time.sleep(3)
            
            while abs(pitch)<60:#True:
                current_time = time.ticks_ms()
                dt = (current_time - last_time) / 1000.0
                last_time = current_time
                eu=imu.euler()
                pitch = eu[1]
 
        #        
                if pitch is not None:
                    control_output = pid_controller.update(pitch, dt)
         
                    factor = 20
                    left_speed =int(control_output * factor)
                    right_speed =int(control_output * factor)
                    drive(right_speed,left_speed)
                    #print(right_speed,left_speed)
                    #time.sleep(0.005)
            free()
 
        except KeyboardInterrupt:
            print("制御終了")
            free()
 
    else:
        print("BNO055の初期化に失敗しました。")

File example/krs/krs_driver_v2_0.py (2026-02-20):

#!/usr/bin/env micropython
# Kondo KRS servo control program
# 2025.4.6
# by T.Nishimura of AiRRC
#
from machine import Pin, I2C, UART
import time
#-------------------------
class KRSdriver():
  def __init__(self):
   #set serial
    self.con = UART(1, baudrate=1250000, tx=Pin(8), rx=Pin(9))
    #self.con = UART(1, baudrate=115200, tx=Pin(8), rx=Pin(9))
    self.con.init(bits=8, parity=0, stop=1,timeout=50)
#
    self.buf2=bytearray(2)
    self.buf3=bytearray(3)
    self.buf4=bytearray(4)
    time.sleep(0.2)
    print("Initialized")
#
  def current_set(self,sid,curr):
    self.buf3[0]=0xC0+sid #cmd+id
    self.buf3[1]=0x03
    self.buf3[2]=curr&0x1F
    self.con.write(self.buf3)
#
    buf_read=self.con.read(2)
    if buf_read is not None:
      if (len(buf_read)==2):
        val=buf_read[1]
        return(val)
      else:
        #print ("ID="+str(sid)+"read few")
        return (9998)
    else:
      #print ("ID="+str(sid)+"read none")
      return(9999)
#----------------------------
# set angle
  def set_position_ret(self,sid,t_pos):
    if(t_pos==0): #set free
      t_pos=0
    elif(t_pos>11500):
      t_pos=11500
    elif(t_pos<3500 ):
      t_pos=3500
  #
    self.buf3[0]=0x80+sid #cmd+id
    self.buf3[1]=(t_pos>>7)&0x7f
    self.buf3[2]=t_pos&0x7f
    self.con.write(self.buf3)
    
    buf_read=self.con.read(3)
    if buf_read is not None:
      #print(len(buf_read))
      if (len(buf_read)==3):
        val=buf_read[2]+(buf_read[1]<<7)
        return(val)
      else:
        #print ("ID="+str(sid)+" read few="+str(len(buf_read)))
        return (9998)
    else:
      print ("ID="+str(sid)+" read none")
      return(9999)
#-----------------------------
# set angle by slave mode
  def set_position(self,sid,t_pos):
# 
    if(t_pos==0): #set free
      t_pos=0
    elif(t_pos>11500):
      t_pos=11500
    elif(t_pos<3500 ) :
      t_pos=3500
  #
    self.buf3[0]=0x80+sid #cmd+id
    self.buf3[1]=(t_pos>>7)&0x7f
    self.buf3[2]=t_pos&0x7f
  # write
    self.con.write(self.buf3)
#------------------------
# read angle at free condition
  def read_position_set_free(self,sid):
    position=self.set_position_ret(sid,0)
    return position
#--------------------------
# read any condition
  def read_position(self,sid):  #from ics3.6
    self.buf2[0]=0xA0+sid #cmd+id
    self.buf2[1]=0x05 #angle
    self.con.write(self.buf2)
    #time.sleep(0.001)
    buf_read=self.con.read(4)
    if buf_read is not None:
      if (len(buf_read)==4):
        val=buf_read[3]|(buf_read[2]<<7)
        return(val)
      else:
        #print ("ID="+str(sid)+" read few")
        #print ("ID="+str(sid)+" set few="+str(len(buf_read)))
        return (9998)
    else:
      print ("ID="+str(sid)+" read none")
      return (9999)
# set ID
  def id_read(self):
    self. buf4[0]=0xFF
    self. buf4[1]=0x00
    self.buf4[2]=0x00
    self.buf4[3]=0x00
    self.con.write(self.buf4)
    buf_read=self.con.read(1)
    if (len(buf_read)==1):
      val=(buf_read[0])&0x1f
      return(val)
    else:
      print ("ID read error")
      return(99)
# set ID 0-31
  def id_set(self,sid):
    cmd1=sid&0x1f 
    cmd=0xE0+cmd1
    self.buf4[0]=cmd    #cmd+id
    self.buf4[1]=0x01
    self.buf4[2]=0x01
    self.buf4[3]=0x01
    self.con.write(self.buf4)
    #time.sleep(0.005)
    buf_read=self.con.read(1)
    if (len(buf_read)==1):
      val=(buf_read[0])&0x1f
      return(val)
    else:
      print ("IDS read error")
      return(99)
#
  def read_memory(self,sid): #2->66
    print("read_memory")
    cmd1=sid&0x1f #sid 0-31
    cmd=0xA0+cmd1
    self.buf2[0]=cmd    #cmd+id
    self.buf2[1]=0x00
    self.con.write(self.buf2)
    #
    buf_read=self.con.read(66) #2-66byte
    #print (len(buf_read))
    if (len(buf_read)==66):
      return(buf_read)
    else:
      print ("memory read error")
      return(99)
    #
  def write_memory(self,sid,write_buf):#3-
    print("write memory ")
    cmd1=sid&0x1f #sid 0-31
    cmd=0xC0+cmd1
    write_buf[0]=cmd    #cmd+id
    write_buf[1]=0x00   #EEPROM
    self.con.write(write_buf)
    
    time.sleep(1)
    #
    buf_read=self.con.read() #2-66byte
    
    #print (len(buf_read))
    if (len(buf_read)==2):
      return(buf_read)
    else:
      print ("memory read error")
      return(99)
      
  #def set_baud(self,baud):
  #    print(" ")
      
# get buttan data of KRS-5FH #id= 31
  def get_5fh(self):
    #print("read button")
    temp=bytearray(4)
    self.buf4[0]=0xbf 
    self.buf4[1]=0x7f
    self.buf4[2]=0x00
    self.buf4[3]=0x02
    self.con.write(self.buf4)
    buf_read=self.con.read(12)
    #print(buf_read)
    if (len(buf_read)==8):
      temp[0]=(buf_read[4])
      temp[1]=(buf_read[5])
      b1=temp[1]|(temp[0]<<8)
      temp[0]=(buf_read[6])
      temp[1]=(buf_read[7])
      b2=temp[1]|(temp[0]<<8)
      return b1,b2
    else:
      print ("5FH read error")
      return 0,0
#---------------------------------    
#
def main():
  sid=1 # left motor
  print(sid,"=",krs.read_position(sid))
  sid=2 # right motor
  print(sid,"=",krs.read_position(sid))
  sid=3 # pan motor
  print(sid,"=",krs.read_position(sid))
  sid=4 # tilt motor
  print(sid,"=",krs.read_position(sid))
  #Arm
  krs.set_position_ret(3,6250)
  krs.set_position_ret(4,7500)
  #直進
  krs.set_position_ret(1,7400)
  krs.set_position_ret(2,7600)
  time.sleep(0.3)
  #回転
  krs.set_position_ret(1,7600)
  krs.set_position_ret(2,7600)
  time.sleep(0.4)
  #stop
  krs.set_position_ret(1,7500)
  krs.set_position_ret(2,7500)
  time.sleep(0.3)
  #free
  krs.read_position_set_free(1)
  krs.read_position_set_free(2)
  krs.read_position_set_free(3)
  krs.read_position_set_free(4)  
#
#------------------------
if __name__ == '__main__':
  print('Start KRS Test')
  krs=KRSdriver()
  #main()
  while(1):
    a,b=krs.get_5fh()
    aa=f'{a:#016b}'
    bb=f'{b:#016b}'
    print(aa,bb)
    #print(a,b)
    time.sleep(0.002)

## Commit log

2026-05-08 Revise Software.md with new IMU sections and links
    Updated links and added sections on IMU control and PID optimization.
2026-05-08 Update IMU section title to include '事例'
